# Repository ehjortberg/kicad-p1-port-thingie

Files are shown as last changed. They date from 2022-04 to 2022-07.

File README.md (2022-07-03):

# P1 Port Thingie
This is a small board to bridge the P1 port of the Swedish electricity meters with Home Assistant.
The level conversion part of the schematics is based on the examples on the [software](https://github.com/psvanstrom/esphome-p1reader) github page.
The rest is basically a 5v to 3.3V LDO and ESP07 required components.

It can be programmed with esphome using a 3.3V ftdi cable or similar. External power via rj12 is probably needed as the ftdi cables usually do not have enough power on 3.3V
Installation guide and software: [https://github.com/psvanstrom/esphome-p1reader](https://github.com/psvanstrom/esphome-p1reader).

Edit the p1reader.yaml and set board: esp01_1m

There is sometimes interference on the RX line when programming so it's preferable to program before adding the transistor.

A box can be 3D Printed. [Download .stl files](https://www.thingiverse.com/thing:5337456)

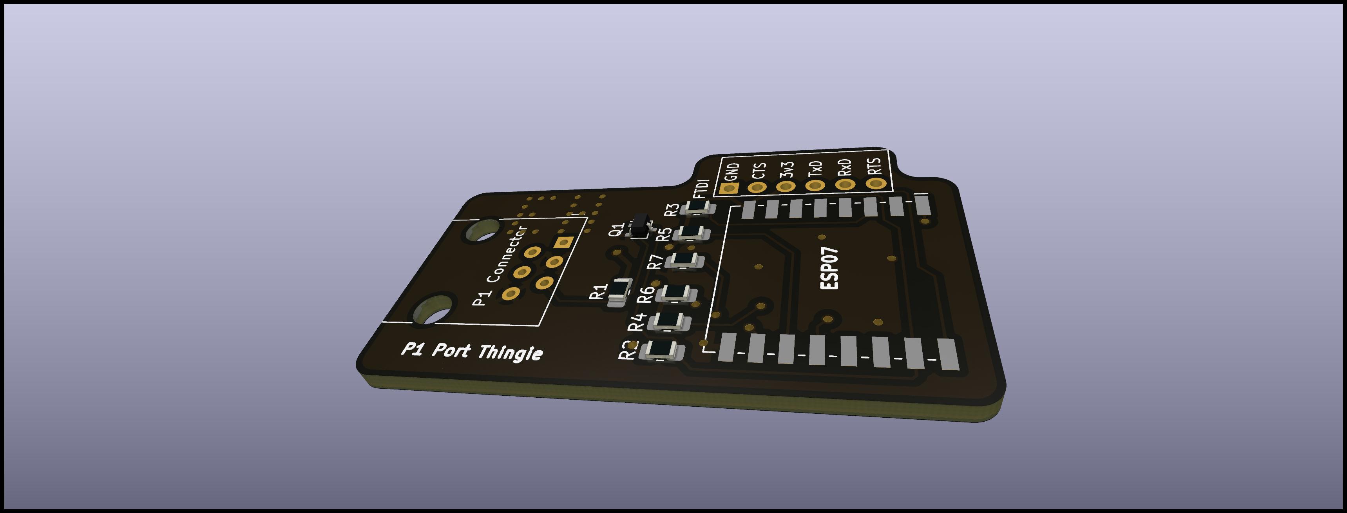
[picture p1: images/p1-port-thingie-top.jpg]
top side

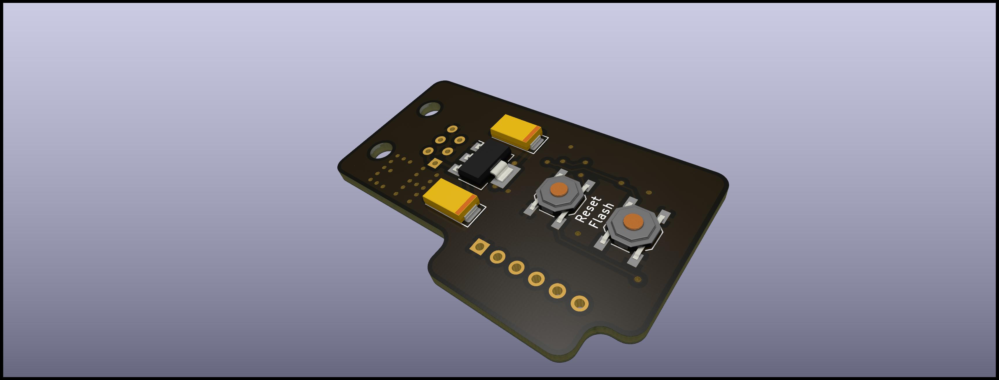
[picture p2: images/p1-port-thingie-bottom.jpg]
bottom side

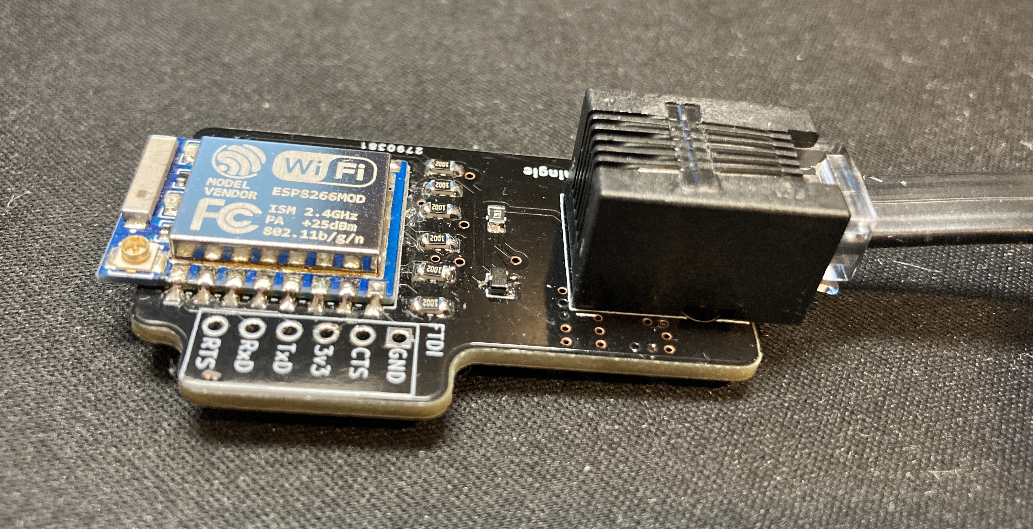
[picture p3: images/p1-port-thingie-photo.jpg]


# BOM

| Reference | Value | Footprint |
| --- | ----- | --- |
|Button1||Button_Switch_SMD:SW_SPST_TL3342|
|Button2||Button_Switch_SMD:SW_SPST_TL3342|
|C1|100nF|Capacitor_Tantalum_SMD:CP_EIA-6032-15_Kemet-U_Pad2.25x2.35mm_HandSolder|
|C2|100nF|Capacitor_Tantalum_SMD:CP_EIA-6032-15_Kemet-U_Pad2.25x2.35mm_HandSolder|
|JP1 Connector|6P6C|Connector_RJ:RJ12_Amphenol_54601|
|Q1|BC817W.115|Package_TO_SOT_SMD:SOT-323_SC-70|
|R1|4K7|Resistor_SMD:R_0805_2012Metric_Pad1.20x1.40mm_HandSolder|
|R2,R3,R4,R5,R6,R7|10K|Resistor_SMD:R_0805_2012Metric_Pad1.20x1.40mm_HandSolder|
|U1|LD1117S33CTR|Package_TO_SOT_SMD:SOT-223-3_TabPin2|
|ESP07|||

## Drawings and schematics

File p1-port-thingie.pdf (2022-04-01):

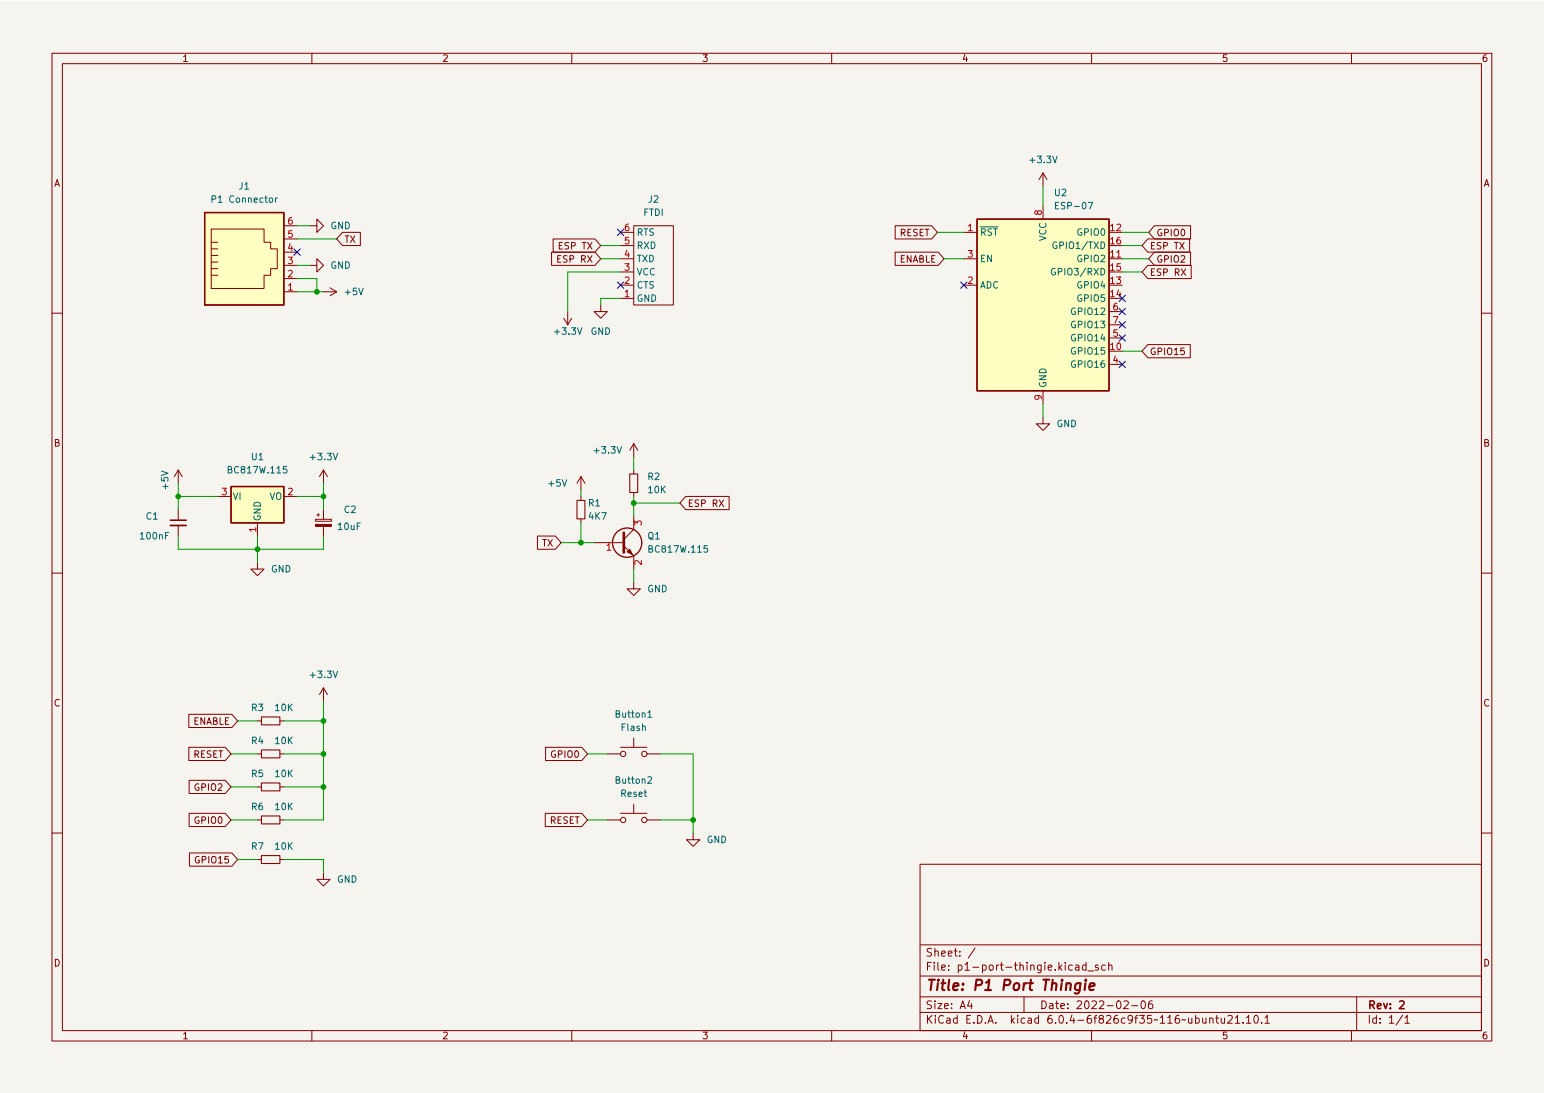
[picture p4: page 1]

ENABLE RESET ESP TX

File: p1-port-thingie.kicad_sch Sheet: /
Id: 1/1 Title: P1 Port Thingie

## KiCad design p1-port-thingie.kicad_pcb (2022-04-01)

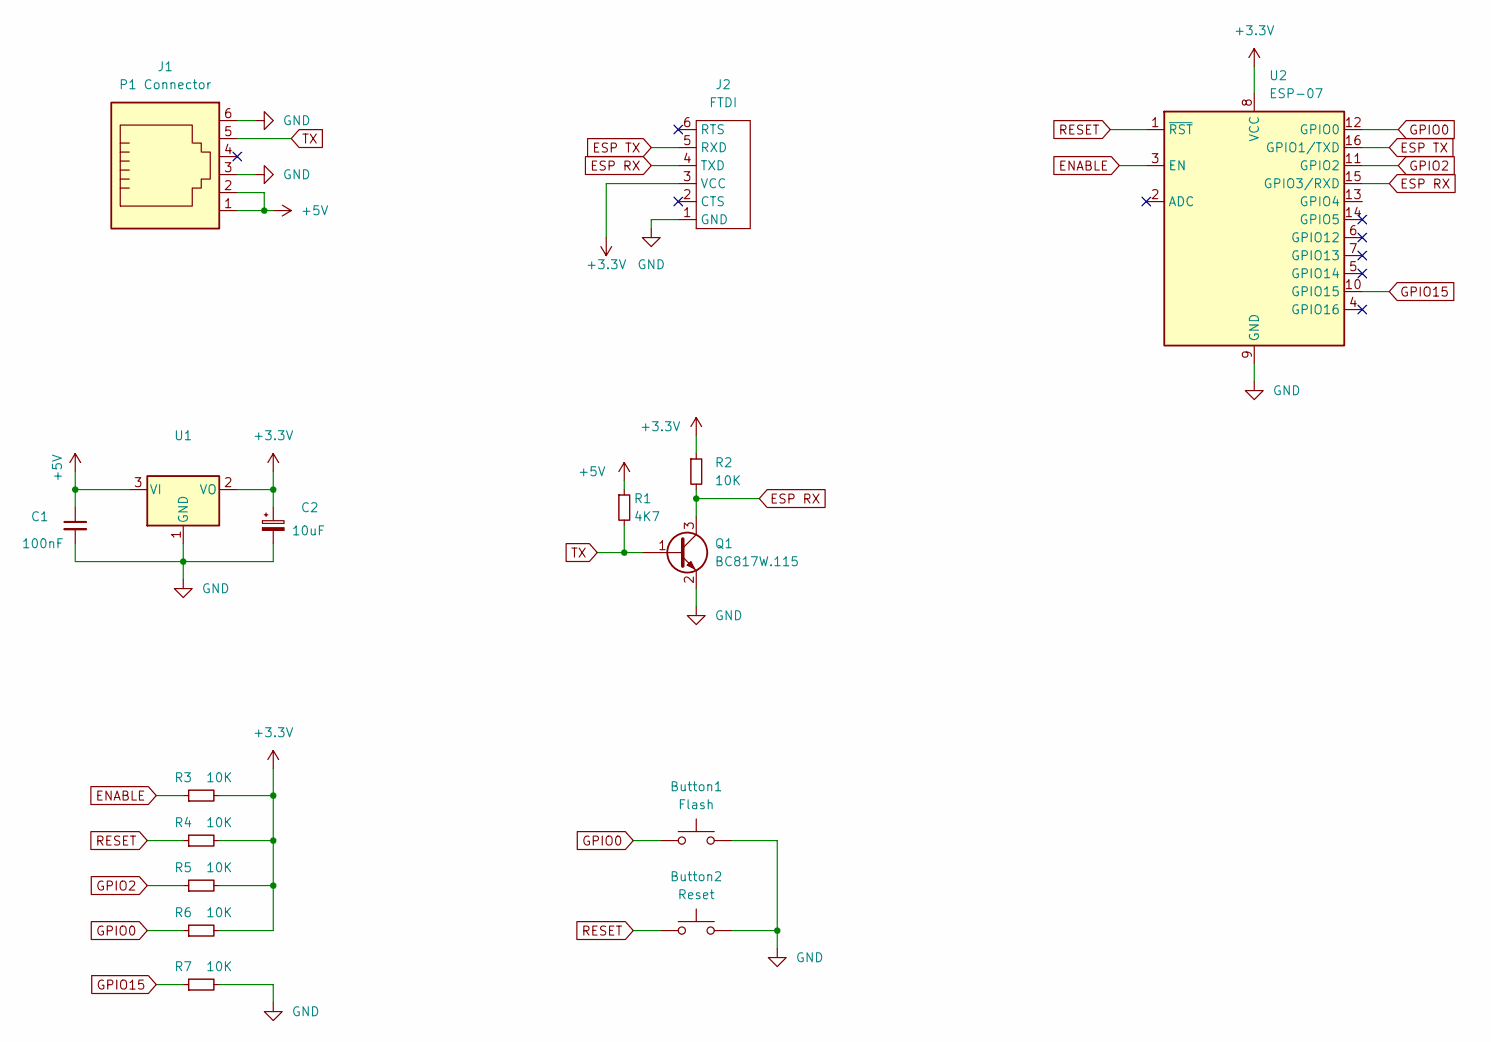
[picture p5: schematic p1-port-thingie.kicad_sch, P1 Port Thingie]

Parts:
Button1: Flash; SW_SPST_TL3342
Button2: Reset; SW_SPST_TL3342
C1: 100nF; CP_EIA-6032-15_Kemet-U_Pad2.25x2.35mm_HandSolder
C2: 10uF; CP_EIA-6032-15_Kemet-U_Pad2.25x2.35mm_HandSolder
J1: P1 Connector; RJ12_Amphenol_54601
J2: FTDI
Q1: BC817W.115; SOT-323_SC-70
R1: 4K7; R_0805_2012Metric_Pad1.20x1.40mm_HandSolder
R2, R3, R4, R5, R6, R7: 10K; R_0805_2012Metric_Pad1.20x1.40mm_HandSolder
U1: (no value)
U2: ESP-07

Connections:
+3V3: C2.1, J2.3 (VCC), R2.1, R3.2, R4.2, R5.2, R6.2, U1.2 (VO), U2.8 (VCC)
+5V: C1.1, J1.1, J1.2, R1.1, U1.3 (VI)
ENABLE: R3.1, U2.3 (EN)
ESP RX: J2.4 (TXD), Q1.3 (C), R2.2, U2.15 (GPIO3/RXD)
ESP TX: J2.5 (RXD), U2.16 (GPIO1/TXD)
GND: Button1.2, Button2.2, C1.2, C2.2, J1.3, J1.6, J2.1 (GND), Q1.2 (E), R7.2, U1.1 (GND), U2.9 (GND)
GPIO0: Button1.1, R6.1, U2.12 (GPIO0)
GPIO2: R5.1, U2.11 (GPIO2)
GPIO15: R7.1, U2.10 (GPIO15)
RESET: Button2.1, R4.1, U2.1 (~RST)
TX: J1.5, Q1.1 (B), R1.2

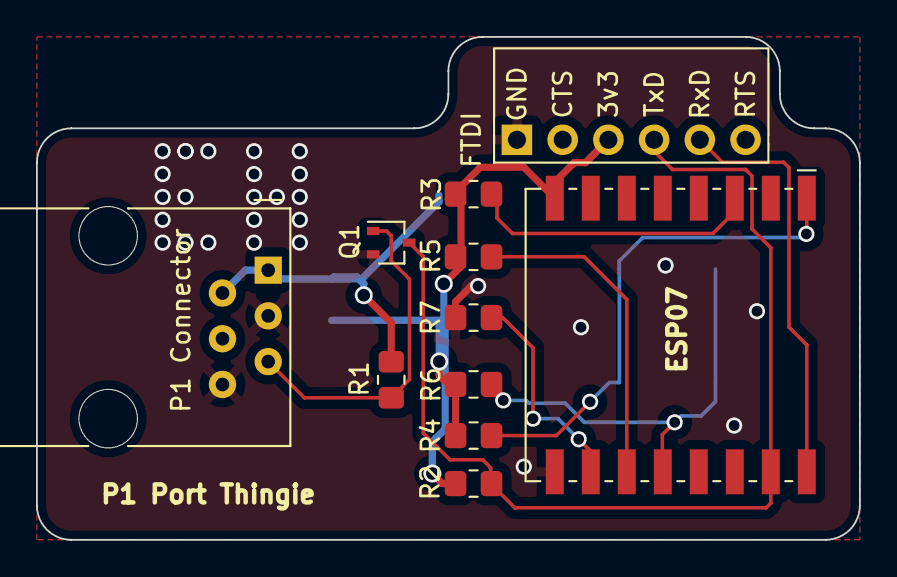
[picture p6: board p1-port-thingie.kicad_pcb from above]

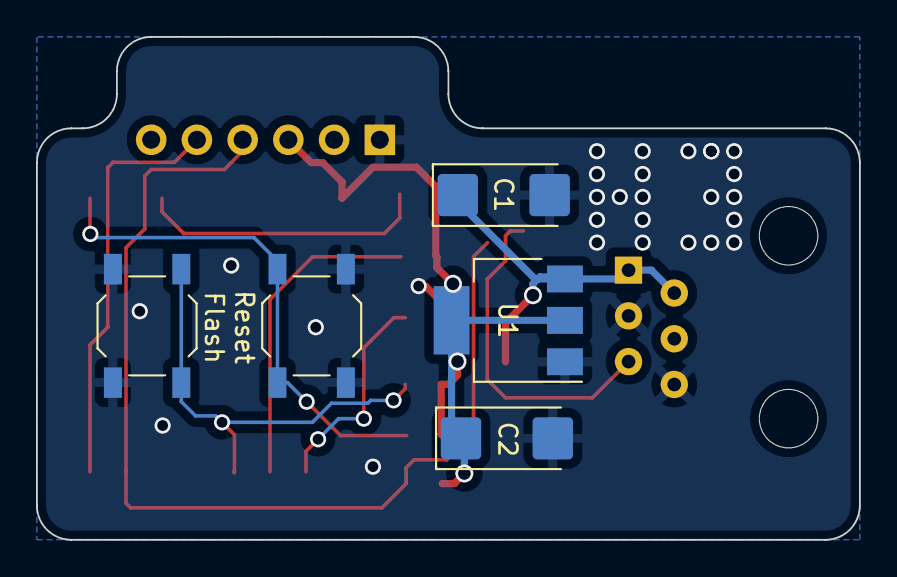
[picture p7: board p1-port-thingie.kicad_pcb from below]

Board: 2 copper layers, 45.7 x 27.9 mm, 16 parts (5 on the bottom side), 11 nets.

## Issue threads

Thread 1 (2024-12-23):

6032 100nF tantalum

riccardo92, 2024-12-23:
I cannot seem to find any 100nF SMD tantalum capacitors in 6032 package. For example, even on kemet.com, applying filters for 0.1uF and 6032 will not give any results. Same for Amazon, Aliexpress etc.

Where can I buy these capacitors? Is there an alternative I can use? Thanks in advance. I'm in Europe btw.

Already had the PCBs made, so redesigning the PCB slightly would be a bit of a shame.

ehjortberg, 2024-12-23:
Hi! Happy that you have chosen to use my build!

I have used Vishay 293D104X9035A2TE3 from tme.eu last time I built one.
They are apparently 1206/3216 but fit well.
The datasheet for the LD1117 actually says 100nF on the Vin and 10uF on Vout but that is not that crucial in this application. So basically anything in the ballpark will work.
I will try to update the instruction when there is some time.

Closed 2024-12-25.

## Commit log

2022-04-01 Take 2
    [p1-port-thingie.kicad_pcb, p1-port-thingie.kicad_sch]
2022-04-01 Link to .stl files on Thingiverse
